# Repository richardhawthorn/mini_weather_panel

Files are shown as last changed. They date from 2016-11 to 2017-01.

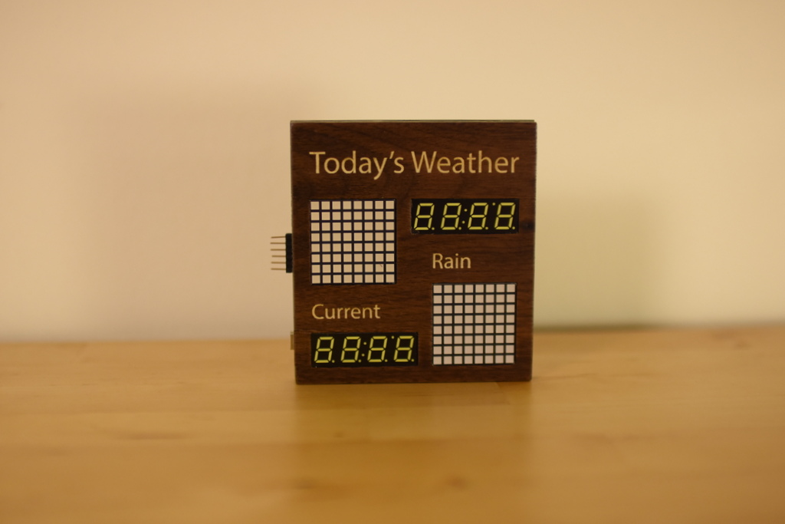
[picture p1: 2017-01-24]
images/07-DSC_0399.JPG

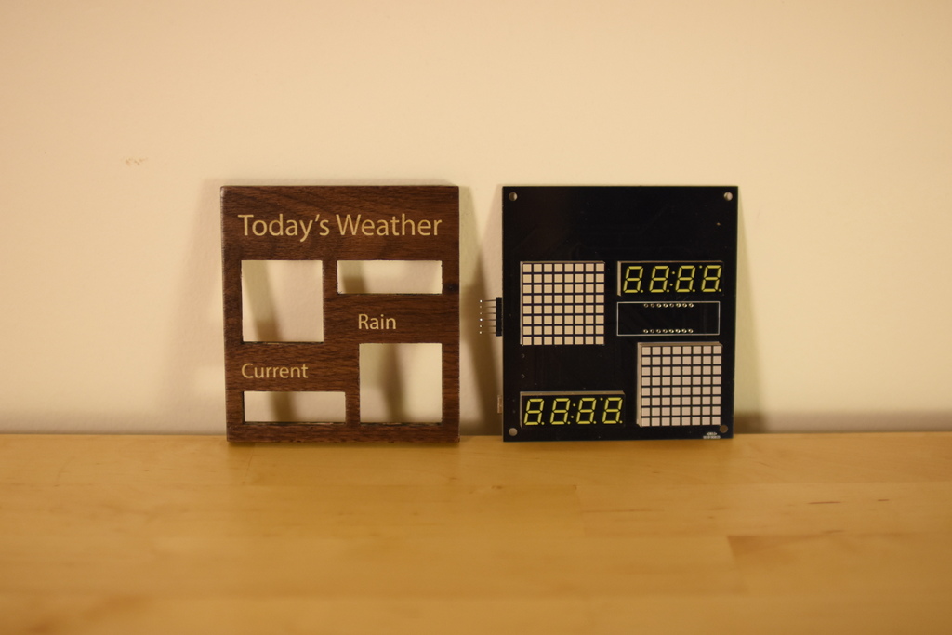
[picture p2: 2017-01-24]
images/06-DSC_0397.JPG

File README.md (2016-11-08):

### Description

Weather screen used to display current and upcoming weather conditions

- Current temperature
- Todays max temperature
- Todays weather icon (sun, cloud etc)
- Rainfall for the next 24 hours

#### Instructions

Config information is stored on the micro SD card, inserted into the back of the board.
Copy the example config.txt file (found in the code folder) onto a blank sd card, and add the relevant config information.

Sign up for a free api key at https://openweathermap.org/api and add that to the config file

This config file is used to set the following:

- Network details
- Open weather map API key
- Location (for weather reporting)
- Units
- Timezone

#### Arduino config

You will need to use the ESP8266 Arduino core to compile and upload this code
https://github.com/esp8266/Arduino

These libraries are also required

- Time - http://www.pjrc.com/teensy/td_libs_Time.html
- Adafruit LED Backpack - https://github.com/adafruit/Adafruit_LED_Backpack
- Adafurit GFX - https://github.com/adafruit/Adafruit-GFX-Library

#### Hardware

- ESP8266 Wifi processor
- 2 x 7 segment LED screens
- 2 x 8x8 matrix LED screens 
- FTDI headers for programming
- Mini USB for power

### License

This work is licensed under a Creative Commons Attribution-ShareAlike 4.0 International License.

<br />
Designed by <a xmlns:cc="http://creativecommons.org/ns#" href="http://www.richardhawthorn.com" property="cc:attributionName" rel="cc:attributionURL" target="_blank">Richard Hawthorn</a><br />
<a rel="license" href="http://creativecommons.org/licenses/by-sa/4.0/" target="_blank">View License</a>

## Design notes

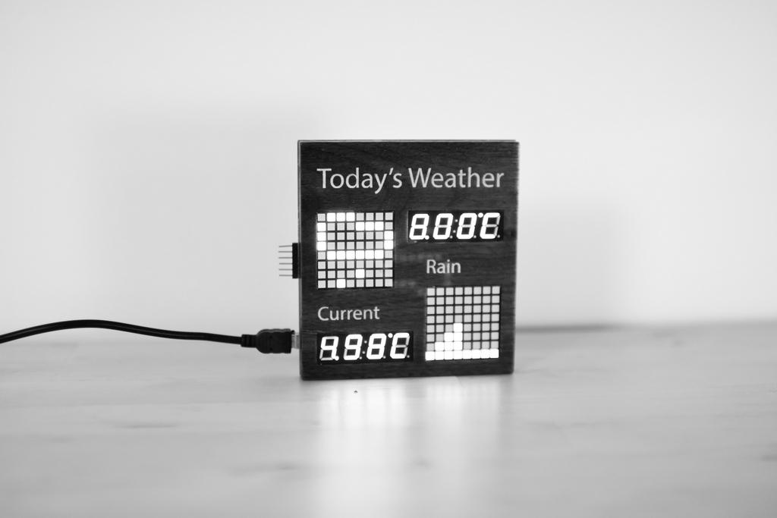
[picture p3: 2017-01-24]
images/09-DSC_0427.JPG

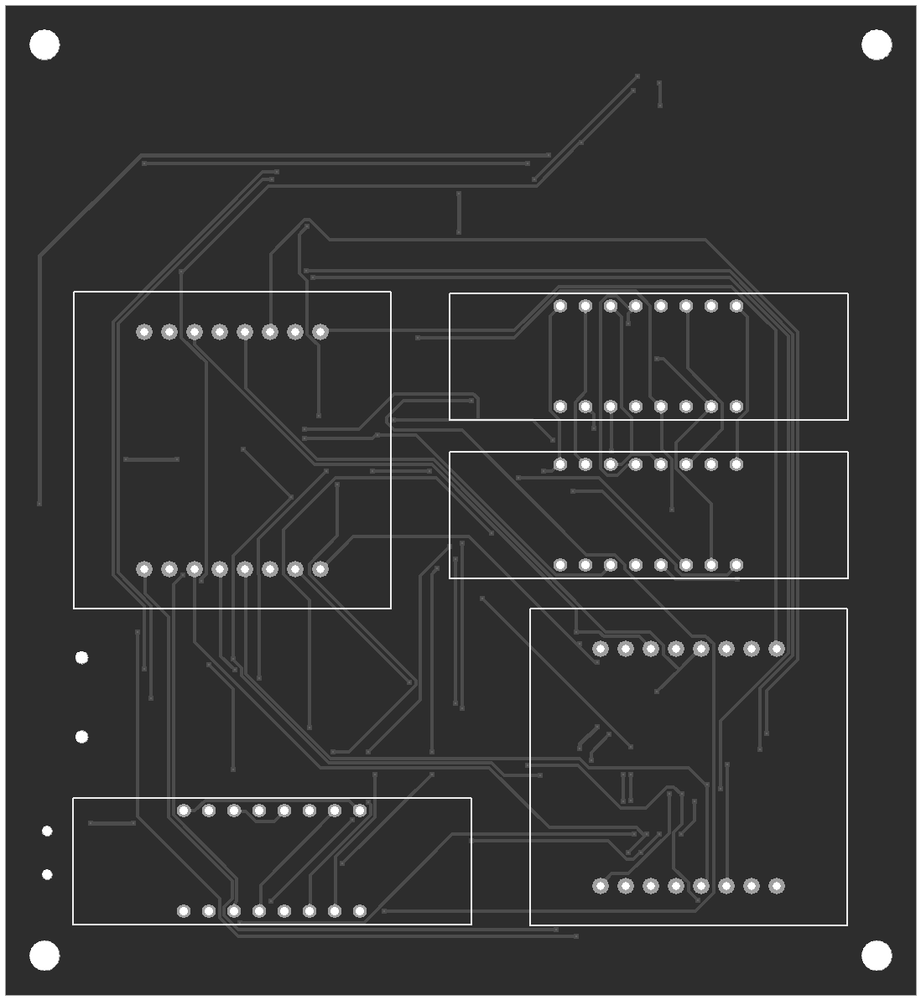
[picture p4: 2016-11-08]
images/pcb_front.png

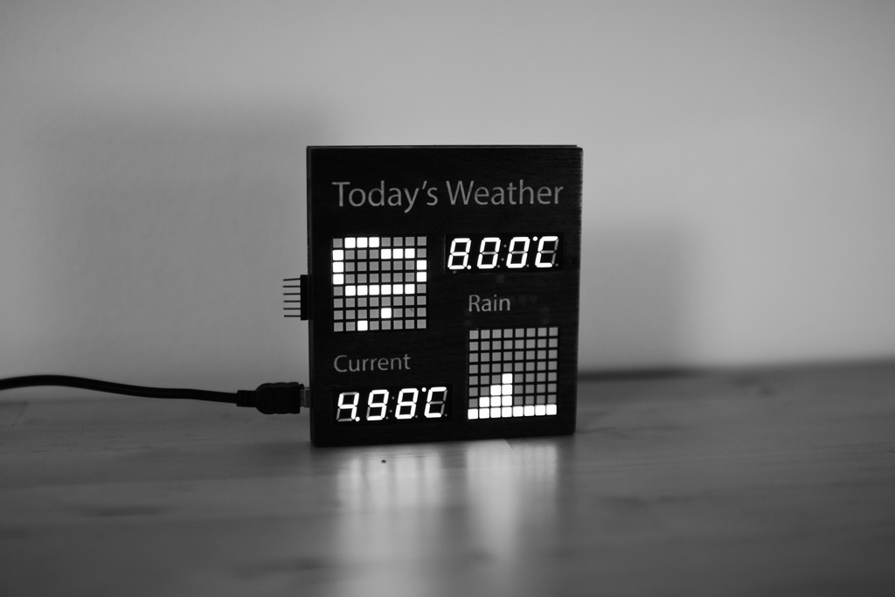
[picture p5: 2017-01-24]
images/08-DSC_0423.JPG

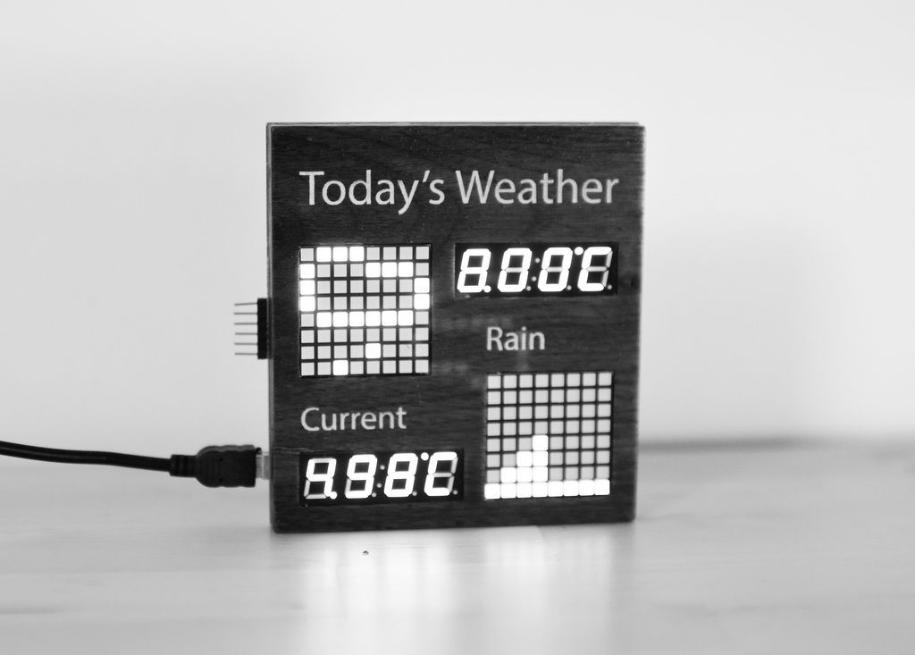
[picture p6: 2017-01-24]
images/2-DSC_0427.JPG

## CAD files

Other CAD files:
front plate/Panel.dxf

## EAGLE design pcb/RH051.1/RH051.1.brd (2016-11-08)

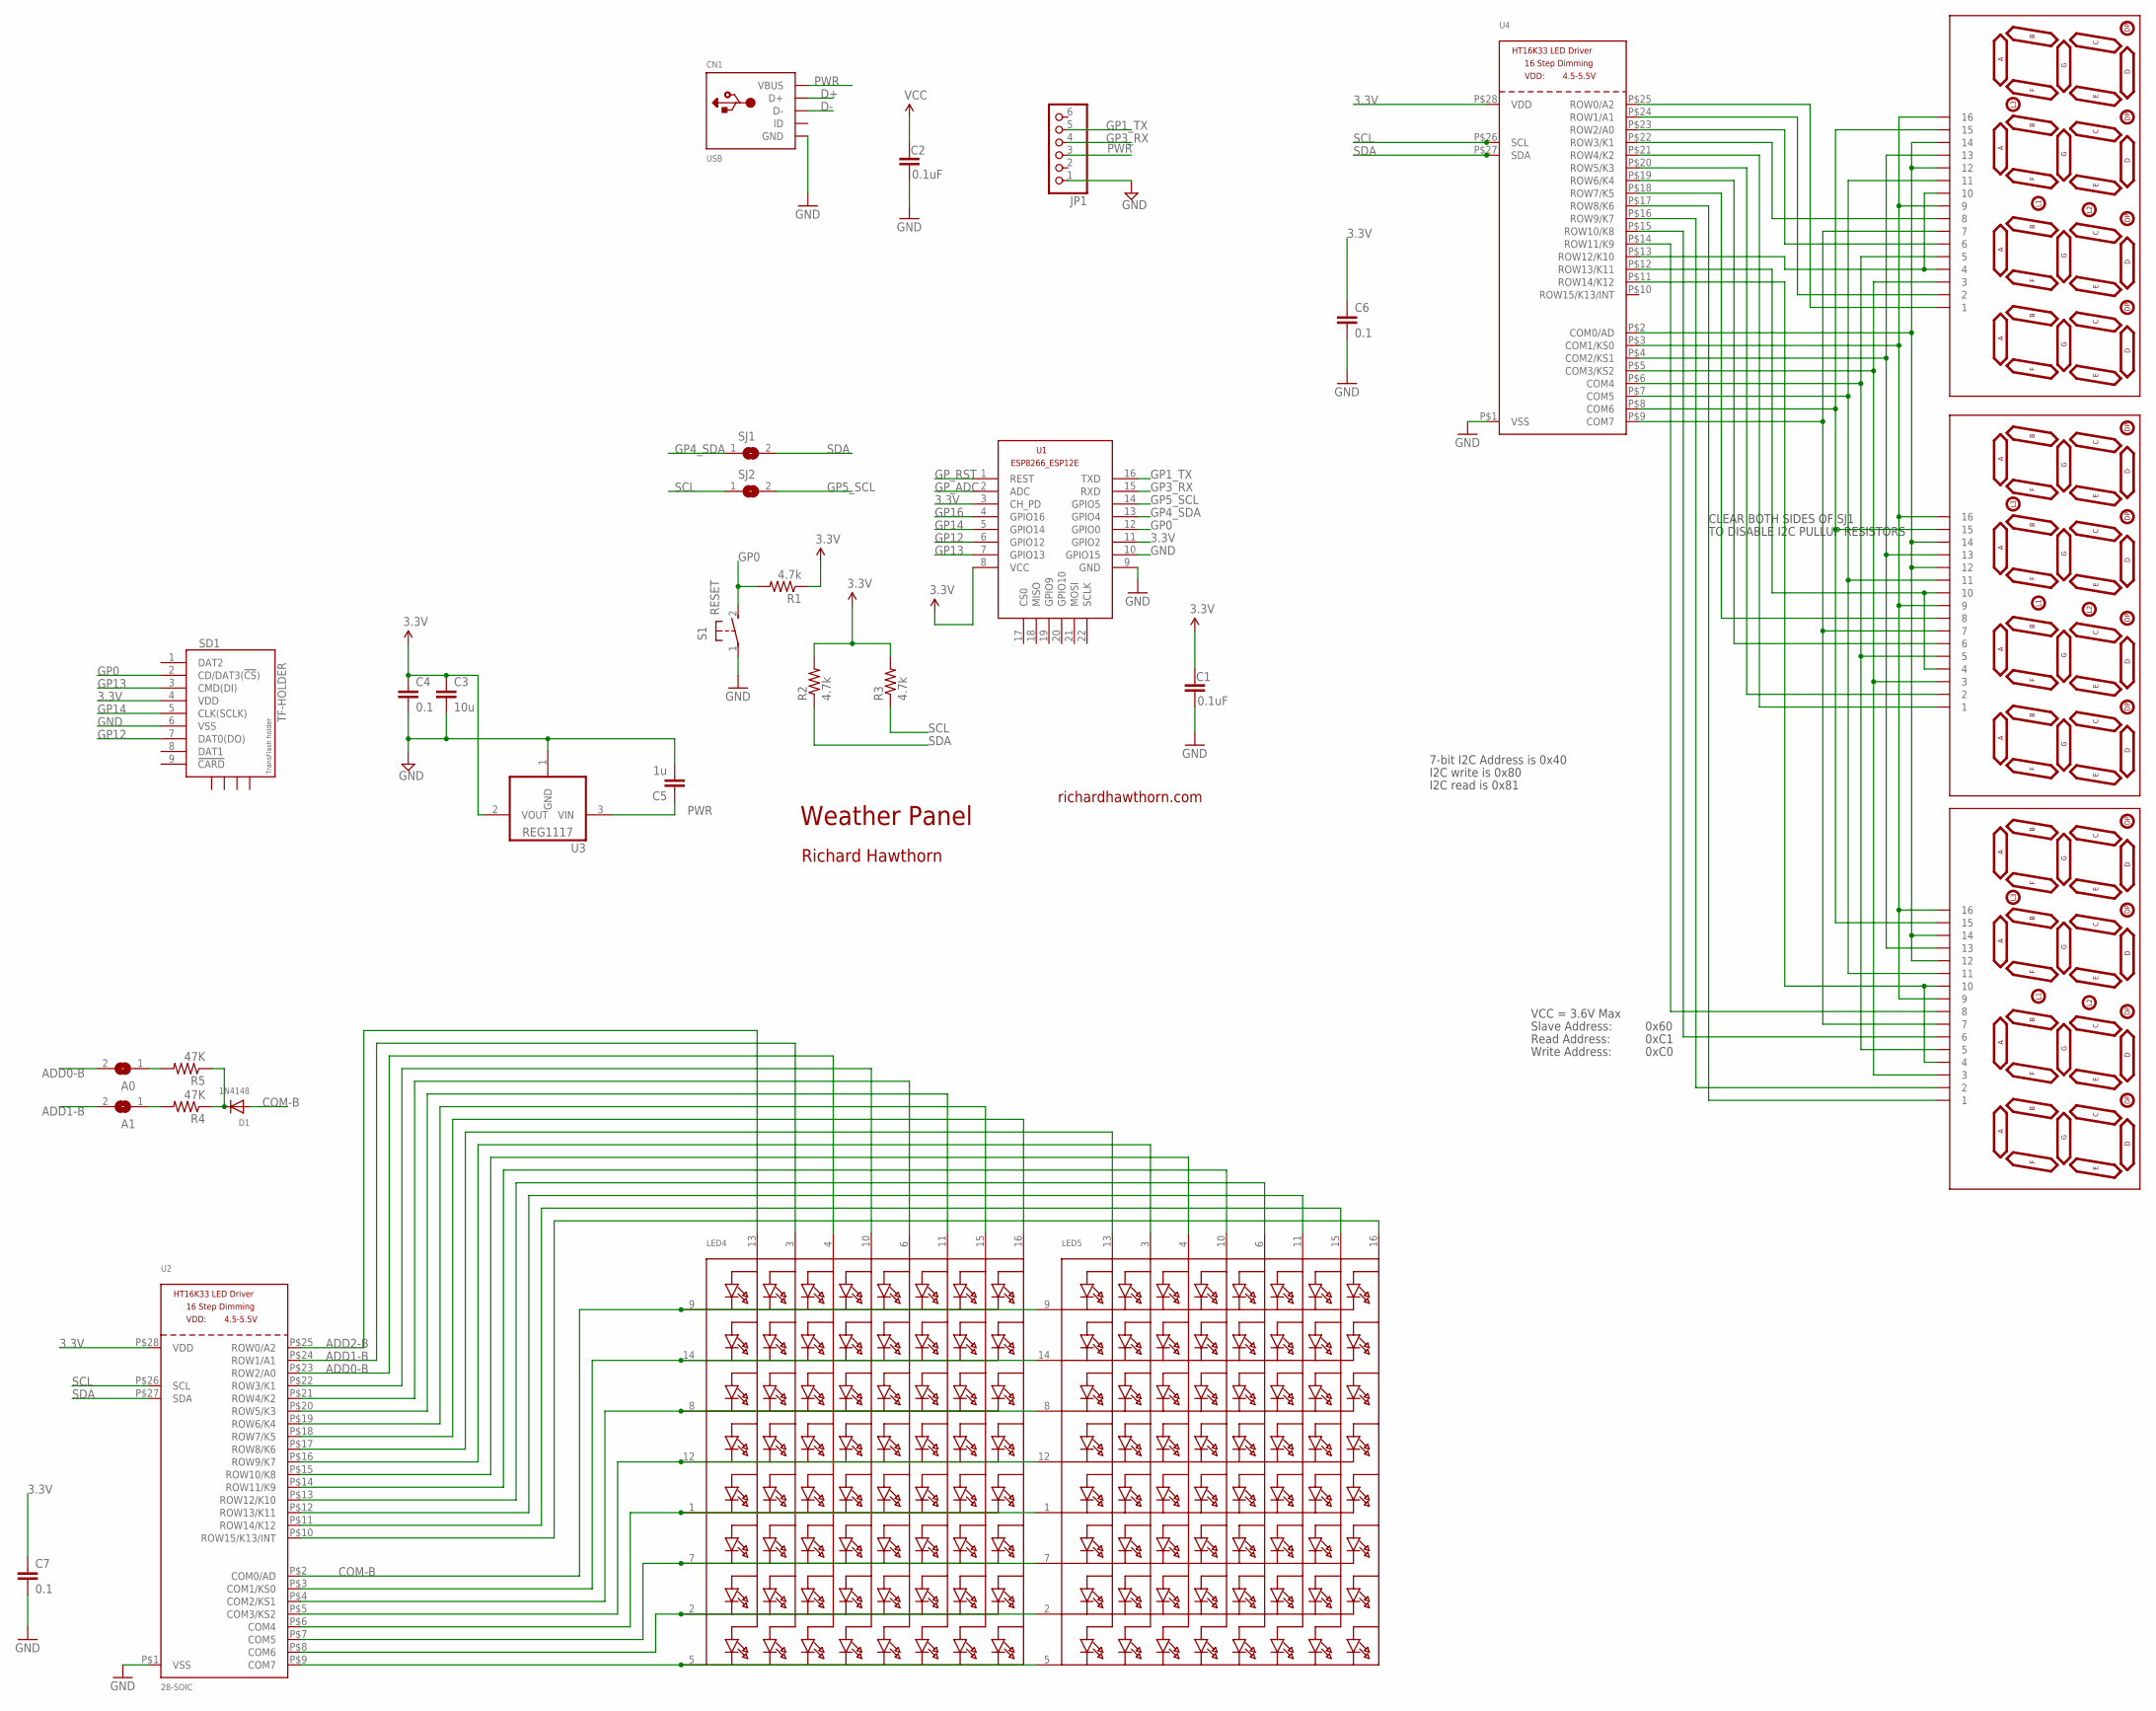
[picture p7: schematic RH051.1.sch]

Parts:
A0, A1: SOLDERJUMPERREFLOW_NOPASTE; SOLDERJUMPER_REFLOW_NOPASTE
C1, C2: 0.1uF; 0603-CAP
C3: 10u; 0805-CAP
C4, C6, C7: 0.1; 0603-CAP
C5: 1u; 0603-CAP
CN1: USB; USB-MINIB
D1: 1N4148; SOD-323F
JP1: PINHD-1X6; 1X06
LED1, LED2, LED3: 7SEG-4DIGIT; SPARKFUN_7-SEGMENT-4DIGIT
LED4, LED5: DISP_SEGMENT_8X8_ROWCATHODEM12A881UR; SEGMENT_BL-M12A881UR
R1, R2, R3: 4.7k; 0805
R4, R5: 47K; R0805
S1: RESET; DTSM-3
SD1: TF-HOLDER; TF-PULL
SJ1, SJ2: SJ
U1: ESP8266-12EESP8266-ESP12E; ESP8266-ESP12E
U2: 28-SOIC; SOP28_300MIL
U3: REG1117; SOT223
U4: HT16K33_SOP28; SOP28_300MIL

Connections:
3.3V: C1.1, C2.1, C3.1, C4.1, C6.1, C7.1, R1.1, R2.2, R3.2, SD1.4 (VDD), U1.3 (CH_PD), U1.8 (VCC), U1.11 (GPIO2), U2.P$28 (VDD), U3.2 (VOUT), U4.P$28 (VDD)
ADD0-A: LED1.6, U4.P$23 (ROW2/A0)
ADD0-B: A0.2, LED4.4 (A3), U2.P$23 (ROW2/A0)
ADD1-A: LED1.2, U4.P$24 (ROW1/A1)
ADD1-B: A1.2, LED4.3 (A2), U2.P$24 (ROW1/A1)
ADD2-A: LED1.1, U4.P$25 (ROW0/A2)
ADD2-B: LED4.13 (A1), U2.P$25 (ROW0/A2)
COM-A: LED1.12, LED1.14, LED2.12, LED2.14, LED3.12, LED3.14, U4.P$2 (COM0/AD)
COM-B: D1.A, LED4.9 (K1), LED5.9 (K1), U2.P$2 (COM0/AD)
D+: CN1.D+
D-: CN1.D-
GND: C1.2, C2.2, C3.2, C4.2, C5.2, C6.2, C7.2, CN1.GND, JP1.1, S1.1, SD1.6 (VSS), U1.9 (GND), U1.10 (GPIO15), U2.P$1 (VSS), U3.1 (GND), U4.P$1 (VSS)
GP0: R1.2, S1.2, SD1.2 (CD/DAT3(!CS!)), U1.12 (GPIO0)
GP1_TX: JP1.5, U1.16 (TXD)
GP3_RX: JP1.4, U1.15 (RXD)
GP4_SDA: SJ1.1, U1.13 (GPIO4)
GP5_SCL: SJ2.2, U1.14 (GPIO5)
GP12: SD1.7 (DAT0(DO)), U1.6 (GPIO12)
GP13: SD1.3 (CMD(DI)), U1.7 (GPIO13)
GP14: SD1.5 (CLK(SCLK)), U1.5 (GPIO14)
GP16: U1.4 (GPIO16)
GP_ADC: U1.2 (ADC)
GP_RST: U1.1 (REST)
unnamed: LED4.5 (K8), LED5.5 (K8), U2.P$9 (COM7)
unnamed: LED4.2 (K7), LED5.2 (K7), U2.P$8 (COM6)
unnamed: LED4.7 (K6), LED5.7 (K6), U2.P$7 (COM5)
unnamed: LED1.9, LED1.16, LED2.9, LED2.16, LED3.9, LED3.16, U4.P$3 (COM1/KS0)
unnamed: LED1.13, LED2.13, LED3.13, U4.P$4 (COM2/KS1)
unnamed: LED1.3, LED2.3, LED3.3, U4.P$5 (COM3/KS2)
unnamed: LED1.5, LED2.5, LED3.5, U4.P$6 (COM4)
unnamed: LED1.11, LED2.11, LED3.11, U4.P$7 (COM5)
unnamed: LED1.15, LED2.15, LED3.15, U4.P$8 (COM6)
unnamed: LED1.7, LED2.7, LED3.7, U4.P$9 (COM7)
unnamed: LED4.1 (K5), LED5.1 (K5), U2.P$6 (COM4)
unnamed: LED4.8 (K3), LED5.8 (K3), U2.P$4 (COM2/KS1)
unnamed: LED4.14 (K2), LED5.14 (K2), U2.P$3 (COM1/KS0)
unnamed: LED1.8, U4.P$22 (ROW3/K1)
unnamed: LED2.1, U4.P$21 (ROW4/K2)
unnamed: LED2.2, U4.P$20 (ROW5/K3)
unnamed: LED2.6, U4.P$19 (ROW6/K4)
unnamed: LED2.8, U4.P$18 (ROW7/K5)
unnamed: LED3.1, U4.P$17 (ROW8/K6)
unnamed: LED3.2, U4.P$16 (ROW9/K7)
unnamed: LED3.6, U4.P$15 (ROW10/K8)
unnamed: LED3.8, U4.P$14 (ROW11/K9)
unnamed: LED1.4, LED1.10, U4.P$13 (ROW12/K10)
unnamed: LED2.4, LED2.10, U4.P$12 (ROW13/K11)
unnamed: LED3.4, LED3.10, U4.P$11 (ROW14/K12)
unnamed: LED5.15 (A7), U2.P$11 (ROW14/K12)
unnamed: LED5.11 (A6), U2.P$12 (ROW13/K11)
unnamed: LED4.16 (A8), U2.P$18 (ROW7/K5)
unnamed: LED4.15 (A7), U2.P$19 (ROW6/K4)
unnamed: LED4.6 (A5), U2.P$21 (ROW4/K2)
unnamed: LED4.10 (A4), U2.P$22 (ROW3/K1)
unnamed: LED5.16 (A8), U2.P$10 (ROW15/K13/INT)
unnamed: LED4.11 (A6), U2.P$20 (ROW5/K3)
unnamed: LED4.12 (K4), LED5.12 (K4), U2.P$5 (COM3/KS2)
unnamed: A1.1, R4.2
unnamed: LED5.13 (A1), U2.P$17 (ROW8/K6)
unnamed: LED5.3 (A2), U2.P$16 (ROW9/K7)
unnamed: LED5.10 (A4), U2.P$14 (ROW11/K9)
unnamed: LED5.4 (A3), U2.P$15 (ROW10/K8)
unnamed: LED5.6 (A5), U2.P$13 (ROW12/K10)
unnamed: A0.1, R5.2
unnamed: D1.C, R4.1, R5.1
PWR: C5.1, CN1.VBUS, JP1.3, U3.3 (VIN)
SCL: R3.1, SJ2.1, U2.P$26 (SCL), U4.P$26 (SCL)
SDA: R2.1, SJ1.2, U2.P$27 (SDA), U4.P$27 (SDA)

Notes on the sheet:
Weather Panel
richardhawthorn.com
Richard Hawthorn
CLEAR BOTH SIDES OF SJ1
TO DISABLE I2C PULLUP RESISTORS
7-bit I2C Address is 0x40
I2C write is 0x80
I2C read is 0x81
VCC = 3.6V Max
Read Address:
Write Address:
Slave Address:
0x60
0xC1
0xC0

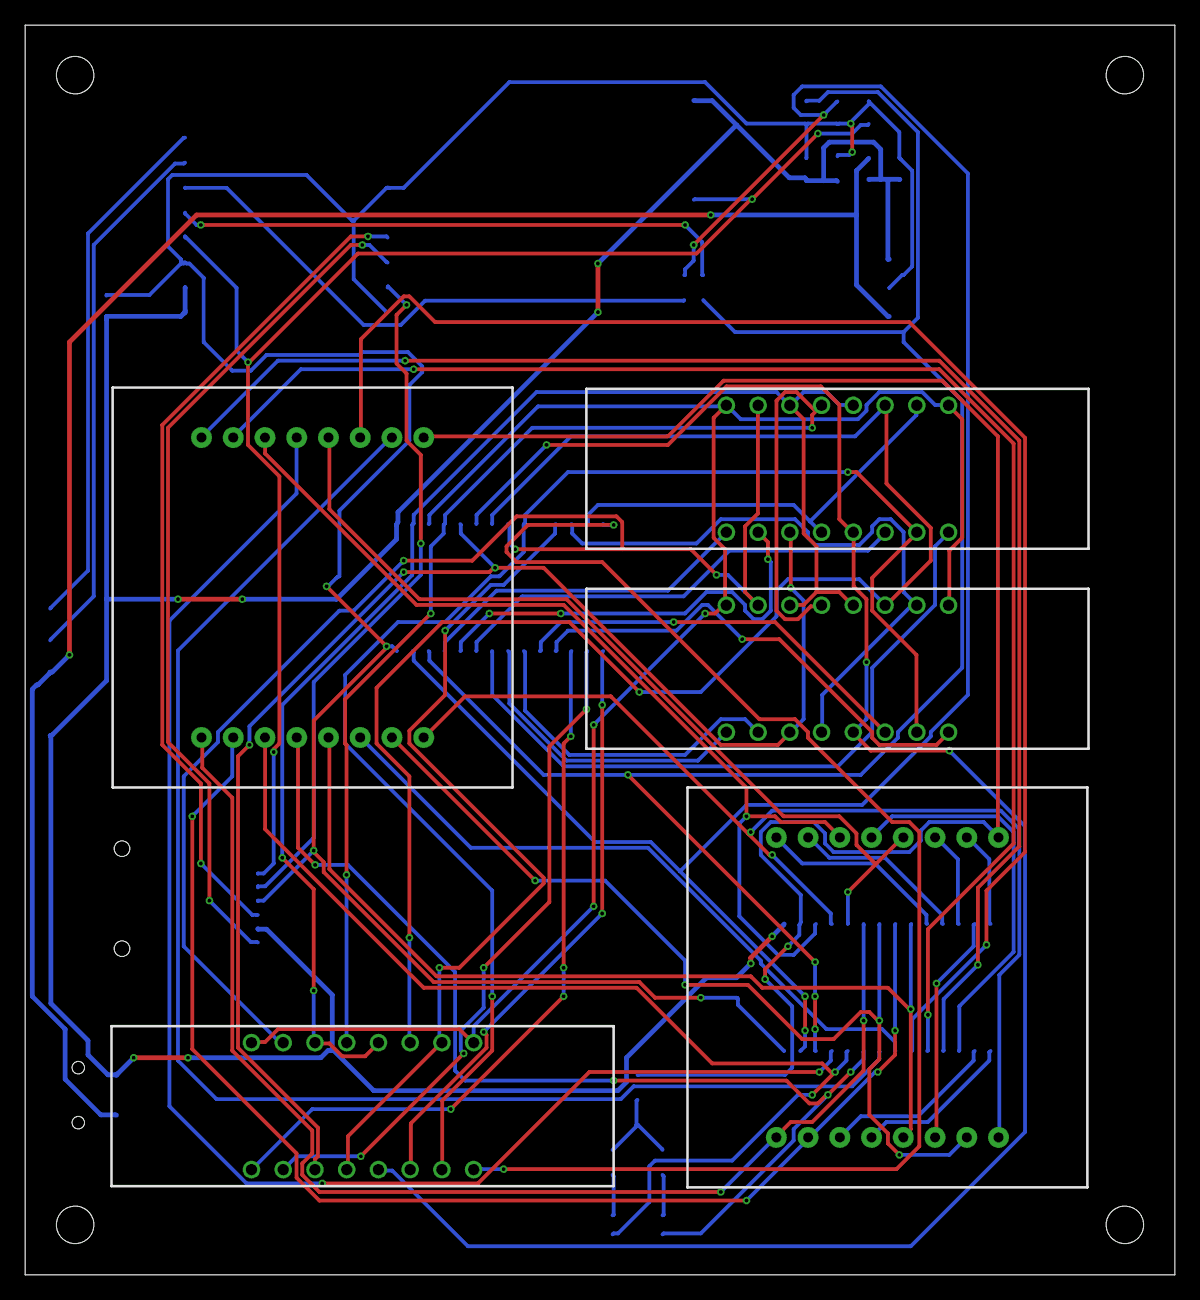
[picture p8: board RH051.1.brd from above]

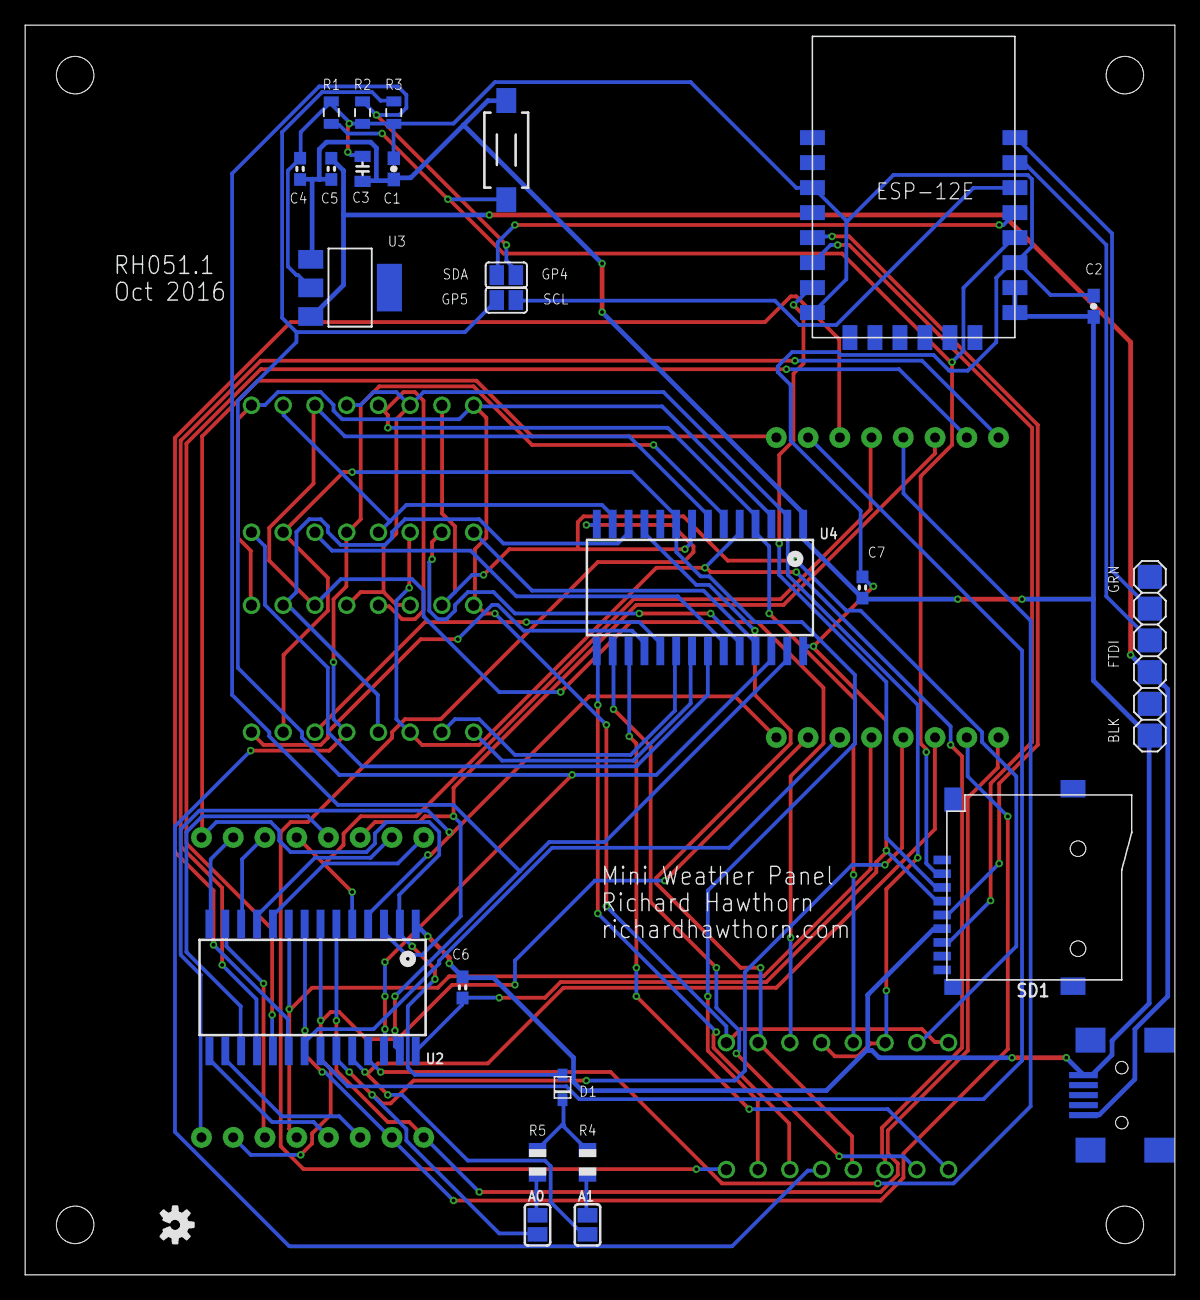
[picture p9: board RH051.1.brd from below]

Board: 2 copper layers, 92.0 x 100.0 mm, 31 parts (26 on the bottom side), 63 nets.

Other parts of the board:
U$3: OSHW-LOGO-S

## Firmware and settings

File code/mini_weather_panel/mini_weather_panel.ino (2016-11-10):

/*
 *  Weather screen
 *  Richard Hawthorn
 *  richardhawthorn.com
 *  2016-11-6 
 *  
 *  Connect to the Open Weather Map API and display current a daily weather conditions
 */

#include <ESP8266WiFi.h>
#include <Wire.h>
#include <TimeLib.h>
#include "Adafruit_LEDBackpack.h"
#include "Adafruit_GFX.h"

Adafruit_LEDBackpack seg7 = Adafruit_LEDBackpack();
Adafruit_8x16matrix matrix = Adafruit_8x16matrix();

#include <SPI.h>
#include <SD.h>

File configFile;

#include "variables.h"
#include "functions.h"


/*
 * Setup the system
 */
void setup() {
  
  Serial.begin(115200);

  setupScreens();
  loadConfigFromSD();
  connectToWifi();
  
}


/*
 * Main loop
 */
void loop() {

  getCurrentWeather();
  getUpcomingWeather();

  //wait until we make the request again
  delay(60000 * sleep_minutes);
}

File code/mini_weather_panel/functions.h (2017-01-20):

/*
 * Function needed for the weather screen
 */

// *******************************************************
// *******************************************************

/*
 * Display a character onto the 7 segment screens
 */

void displayCharacter(int offset, int character, int number){

  offset = offset + 4 - character;
  
  if (number == 0){
    seg7.displaybuffer[0] |= 0x0001 << offset;
    seg7.displaybuffer[1] |= 0x0001 << offset;
    seg7.displaybuffer[2] |= 0x0001 << offset;
    seg7.displaybuffer[3] |= 0x0001 << offset;
    seg7.displaybuffer[4] |= 0x0001 << offset;
    seg7.displaybuffer[5] |= 0x0001 << offset;
  }

  if (number == 1){
    seg7.displaybuffer[1] |= 0x0001 << offset;
    seg7.displaybuffer[2] |= 0x0001 << offset;
  }

  if (number == 2){
    seg7.displaybuffer[0] |= 0x0001 << offset;
    seg7.displaybuffer[1] |= 0x0001 << offset;
    seg7.displaybuffer[3] |= 0x0001 << offset;
    seg7.displaybuffer[4] |= 0x0001 << offset;
    seg7.displaybuffer[6] |= 0x0001 << offset;
  }

  if (number == 3){
    seg7.displaybuffer[0] |= 0x0001 << offset;
    seg7.displaybuffer[1] |= 0x0001 << offset;
    seg7.displaybuffer[2] |= 0x0001 << offset;
    seg7.displaybuffer[3] |= 0x0001 << offset;
    seg7.displaybuffer[6] |= 0x0001 << offset;
  }

  if (number == 4){
    seg7.displaybuffer[1] |= 0x0001 << offset;
    seg7.displaybuffer[2] |= 0x0001 << offset;
    seg7.displaybuffer[5] |= 0x0001 << offset;
    seg7.displaybuffer[6] |= 0x0001 << offset;
  }

  if (number == 5){
    seg7.displaybuffer[0] |= 0x0001 << offset;
    seg7.displaybuffer[2] |= 0x0001 << offset;
    seg7.displaybuffer[3] |= 0x0001 << offset;
    seg7.displaybuffer[5] |= 0x0001 << offset;
    seg7.displaybuffer[6] |= 0x0001 << offset;
  }

  if (number == 6){
    seg7.displaybuffer[0] |= 0x0001 << offset;
    seg7.displaybuffer[2] |= 0x0001 << offset;
    seg7.displaybuffer[3] |= 0x0001 << offset;
    seg7.displaybuffer[4] |= 0x0001 << offset;
    seg7.displaybuffer[5] |= 0x0001 << offset;
    seg7.displaybuffer[6] |= 0x0001 << offset;
  }

  if (number == 7){
    seg7.displaybuffer[0] |= 0x0001 << offset;
    seg7.displaybuffer[1] |= 0x0001 << offset;
    seg7.displaybuffer[2] |= 0x0001 << offset;
  }

  if (number == 8){
    seg7.displaybuffer[0] |= 0x0001 << offset;
    seg7.displaybuffer[1] |= 0x0001 << offset;
    seg7.displaybuffer[2] |= 0x0001 << offset;
    seg7.displaybuffer[3] |= 0x0001 << offset;
    seg7.displaybuffer[4] |= 0x0001 << offset;
    seg7.displaybuffer[5] |= 0x0001 << offset;
    seg7.displaybuffer[6] |= 0x0001 << offset;
  }

  if (number == 9){
    seg7.displaybuffer[0] |= 0x0001 << offset;
    seg7.displaybuffer[1] |= 0x0001 << offset;
    seg7.displaybuffer[2] |= 0x0001 << offset;
    seg7.displaybuffer[3] |= 0x0001 << offset;
    seg7.displaybuffer[5] |= 0x0001 << offset;
    seg7.displaybuffer[6] |= 0x0001 << offset;
  }

}

/*
 * Display a number on the 7 segment screens
 */
void displayNumber(int screen, int number){

  int offset = (screen-1) * 4;

  displayCharacter(offset, 1, number%10);
  displayCharacter(offset, 2, (number%100)/10);
  displayCharacter(offset, 3, (number%1000)/100);
  displayCharacter(offset, 4, (number%10000)/1000);
    
}

/*
 * Display the temperature on the 7 segment screens
 */
void displayTemp(int screen, float val){

  int offset = (screen-1) * 4;
  int number = 0;
  int decimalChar = 0;
  int negative = false;

  if (val >= 100){
    number = (int) (val * 10);
    decimalChar = 0;
  } else if (val >= 10){
    number = (int) (val * 100);
    decimalChar = 2;
  } else if (val >= 0){
    number = (int) (val * 1000);
    decimalChar = 1;
  } else if (val >= -10){
    number = (int) (val * 1000);
    decimalChar = 2;
    negative = true;
    number = 0 - ( (int) (val * 100) );
  } else if (val >= -100){
    number = (int) (val * 100);
    decimalChar = 0;
    negative = true;
    number = 0 - ( (int) (val * 10) );
  } else {
    number = 0;
  }

  //display second and third numbers
  displayCharacter(offset, 2, (number%100)/10);
  displayCharacter(offset, 3, (number%1000)/100);

  //is this a negative number?
  if (negative == true){
    //display negative sign
    seg7.displaybuffer[6] |= 0x0001 << offset;
  } else {
    //display first number
    displayCharacter(offset, 4, (number%10000)/1000);
  }

  if (sd_units == "c"){
    seg7.displaybuffer[0] |= 0x0001 << offset + 3;
    seg7.displaybuffer[3] |= 0x0001 << offset + 3;
    seg7.displaybuffer[4] |= 0x0001 << offset + 3;
    seg7.displaybuffer[5] |= 0x0001 << offset + 3;
  } else {
    seg7.displaybuffer[0] |= 0x0001 << offset + 3;
    seg7.displaybuffer[4] |= 0x0001 << offset + 3;
    seg7.displaybuffer[5] |= 0x0001 << offset + 3;
    seg7.displaybuffer[6] |= 0x0001 << offset + 3;
  }

  //decimal place
  if (decimalChar > 0){
    seg7.displaybuffer[7] |= 0x0001 << offset + decimalChar - 1;
  }

  //degrees symbol
  seg7.displaybuffer[1] |= 0x0001 << screen + 11;

}

/*
 * Clear the screen buffers
 */
void clearScreenBuffer(){

  seg7.displaybuffer[0] = 0x0000;
  seg7.displaybuffer[1] = 0x0000;
  seg7.displaybuffer[2] = 0x0000;
  seg7.displaybuffer[3] = 0x0000;
  seg7.displaybuffer[4] = 0x0000;
  seg7.displaybuffer[5] = 0x0000;
  seg7.displaybuffer[6] = 0x0000;
  seg7.displaybuffer[7] = 0x0000;

  matrix.clear();      // clear display
  
}

/*
 * Plot a chart of rain over the next 24 hours
 */
void plotRain(){

  for (int i = 0; i < 8; i++){
      if (rainChart[i] > 0){
        matrix.drawLine(i + 8, 7, i + 8, 7 - rainChart[i] + 1, LED_ON);
      }
  }
  
}

/*
 * Write the data to the led screens
 */
void writeToScreen(){
  
  seg7.writeDisplay();
  matrix.writeDisplay(); 
  
}

/*
 * Load the settings from the SD card
 */
void loadConfigFromSD(){

  char character;
  int line = 1;
  
  if (!SD.begin(0)) {
    matrix.drawBitmap(0, 0, no, 8, 8, LED_ON);
    matrix.drawBitmap(8, 0, card, 8, 8, LED_ON);
    writeToScreen();
    return;
  }

  configFile = SD.open("config.txt");
  if (configFile){

    while (configFile.available()) {
      character = (char) configFile.read();

       Serial.print(character);

      if (character == '\n'){
        line++;
      } else if (character == '\r'){
        //do nothing 
      } else {
      
        if (line == 2){
          sd_ssid = sd_ssid + character;
        } else if (line == 4){
          sd_password = sd_password + character;
        } else if (line == 6){
          sd_apikey = sd_apikey + character;
        } else if (line == 8){
          sd_location = sd_location + character;
        } else if (line == 10){
          sd_units = sd_units + character;
        } else if (line == 12){
          sd_timezone = sd_timezone + character;
        }
      } 
    }
    // close the file:
    configFile.close();

  }

  /*
  Serial.println(sd_ssid);
  Serial.println(sd_password);
  Serial.println(sd_apikey);
  Serial.println(sd_location);
  Serial.println(sd_units);
  Serial.println(sd_timezone);
  */
  
}
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

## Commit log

2016-11-08 Add PCB and readme
    [RH051.1.brd, RH051.1.sch]
2016-11-08 Adding front panel
    [Panel.dxf]
2016-11-08 Adding Arduino code
    [config.txt]
2016-11-10 update Arduino code header

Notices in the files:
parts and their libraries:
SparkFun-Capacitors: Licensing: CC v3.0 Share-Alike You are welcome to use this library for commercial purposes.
